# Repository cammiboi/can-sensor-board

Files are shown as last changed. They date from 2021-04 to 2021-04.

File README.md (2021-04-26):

# can-sensor-board

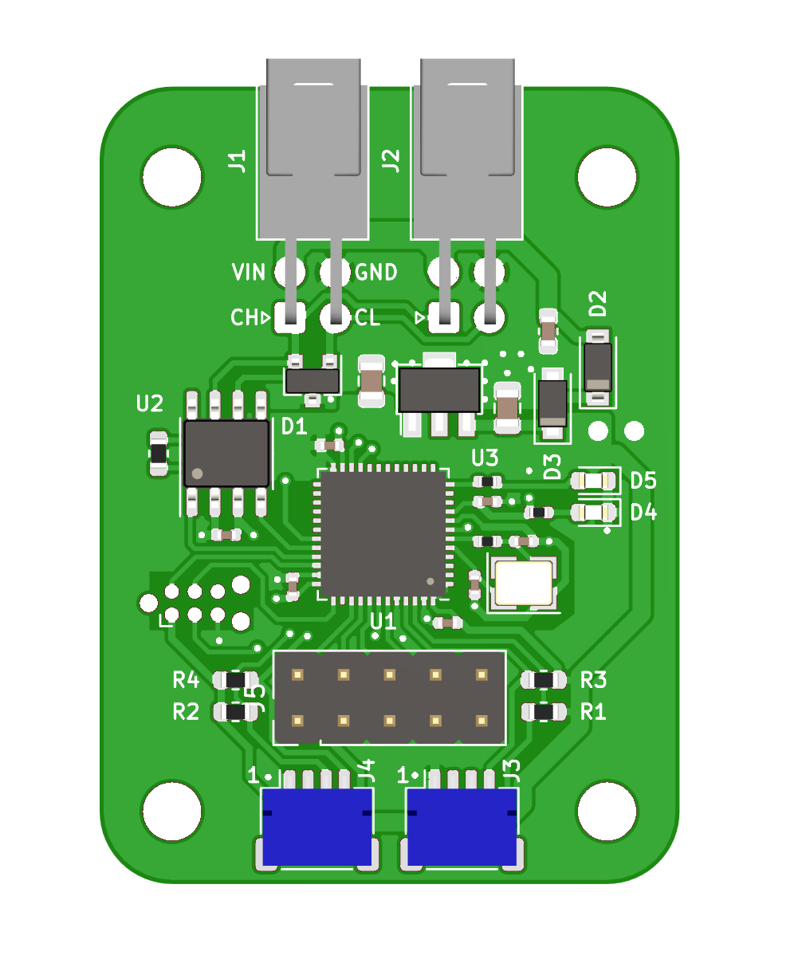
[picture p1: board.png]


# Pupose
To attach any I2C sensor to a CAN bus.

# Requirements
* Powered by 5-16V DC
* Input and output connector (daisy chain boards)
* Set address on board
* I2C 4 pin connector to quickly connect different sensor boards
* Programming header
* ESD protection on connector pins

# Pinout
### CAN and Power Connectors (J1 and J2)

Both of these connectors are the same, you can plug input OR output in to either one.

Wire connector: Molex 1053081204

| Pin Number | Function |
|--|--|
|1| CAN H |
|2 | CAN L |
|3 | VIN |
|4 | GND|

### I2C Connectors (J3 and J4)

Works with Sensor boards that have Adafruit STEMMA QT or Sparkfun QWIIC connector.

| Pin Number | Function |
|--|--|
|1| GND |
|2 | 3V3 |
|3 | SDA |
|4 | SCL|

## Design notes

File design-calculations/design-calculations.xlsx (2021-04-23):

https://datasheet.lcsc.com/lcsc/1912111437_TAE-Zhejiang-Abel-Elec-TAXM8M4RDBCCT2T_C400090.pdf
http://www.raltron.com/wp-content/uploads/2016/11/Oscillator-design-guide-for-STM8S-STM8A-and-STM32-microcontrollers-ST-MICRO-1.pdf
1. Check cystal gain margin
ESR | 250 | ohm
f | 8000000 | Hz
Co | 7e-12 | F | shunt cap
Cl | 1e-11 | F | norm load cap
gmcrit | 0.73 | mA/V
gm | 10 | mA/V
gmargin | 13.7 |  | ensure >5
2. Calculate load cap value
Cs | 5e-12 | F | stray pcb cap
Cl | 1e-11
3. Calculate drive level and Rext
Initial estimation of Rext
Rext(est) | 1989.436789 | ohm

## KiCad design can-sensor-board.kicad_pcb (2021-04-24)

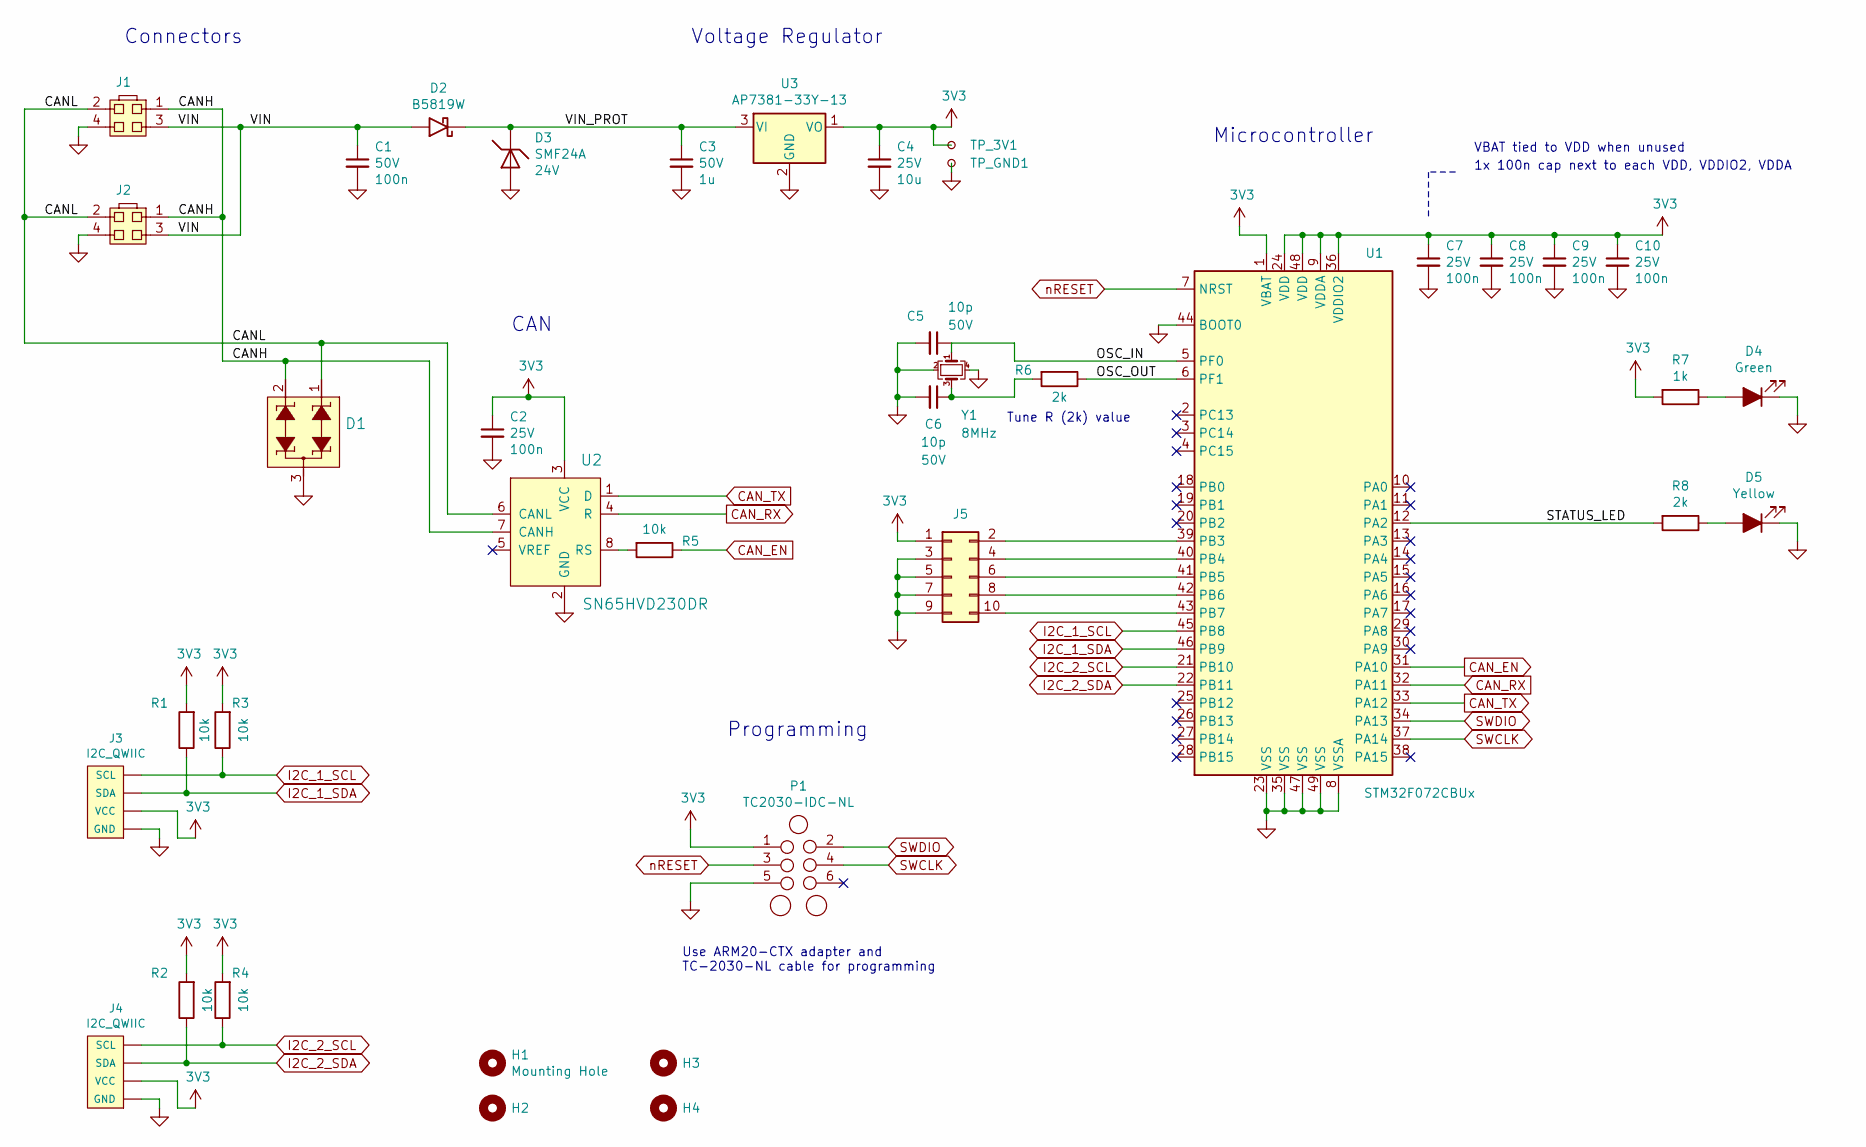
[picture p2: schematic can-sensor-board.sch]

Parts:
C1: C_0603_50V_X7R_100n; C_0603_1608Metric; Voltage 50V; Part Number CL10B104KB8NFNC; JLC C14663
C2, C7, C8, C9, C10: C_0402_25V_X7R_100n; C_0402_1005Metric; Voltage 25V; Manufacturer Part Number CL05B104KA5NNNC; JLC C100072
C3: C_0805_50V_X7R_1u; C_0805_2012Metric; Voltage 50V; Part Number CL21B105KBFNNNG; JLC C28323
C4: C_0805_25V_X5R_10u; C_0805_2012Metric; Voltage 25V; Part Number CL21A106KAYNNNG; JLC C15850
C5, C6: C_0402_50V_COG_10p; C_0402_1005Metric; Voltage 50V; JLC C32949
D1: PESD2CAN_215; SOT-23; MPN PESD2CAN,215; Digi-Key_PN 1727-3891-1-ND
D2: B5819W; D_SOD-123; Voltage 40V; JLC C8598
D3: SMF24A; D_SOD-123F; JLC C169430
D4: LED_0603_Green; LED_0603_1608Metric; JLC C72043
D5: LED_0603_Yellow; LED_0603_1608Metric; JLC C72038
H1, H2, H3, H4: Mounting Hole; MountingHole_3.2mm_M3; JLCPCB_IGNORE Yes
J1, J2: 105314-1104; Molex_Nano-Fit_105314-xx04_2x02_P2.50mm_Horizontal; JLCPCB_IGNORE Yes
J3, J4: I2C_QWIIC; JST_SH_SM04B-SRSS-TB_1x04-1MP_P1.00mm_Horizontal; Part Number SM04B-SRSS-TB(LF)(SN); JLC C395301
J5: Conn_02x05_Odd_Even; PinHeader_2x05_P2.54mm_Vertical; JLCPCB_IGNORE Yes
P1: TC2030-IDC-NL; Tag-Connect_TC2030-IDC-NL_2x03_P1.27mm_Vertical; JLCPCB_IGNORE Yes
R1, R2, R3, R4, R5: R_0603_10k_1; R_0603_1608Metric; JLC C25804
R6, R8: R_0402_2k_1; R_0402_1005Metric; JLC C4109
R7: R_0402_1k_1; R_0402_1005Metric; JLC C11702
TP_3V1: TestPoint_Small; TestPoint_Pad_D1.00mm; JLCPCB_IGNORE Yes
TP_GND1: TestPoint_Small; TestPoint_Pad_D1.00mm; JLCPCB_IGNORE Yes
U1: STM32F072CBUx; QFN-48-1EP_7x7mm_P0.5mm_EP5.6x5.6mm; JLC C92504
U2: SN65HVD230DR; SOIC-8_3.9x4.9mm_P1.27mm; MPN SN65HVD230DR; Digi-Key_PN 296-11654-1-ND
U3: AP7381-33Y-13; SOT-89-3; JLC C460411
Y1: TAXM8M4RDBCCT2T; Crystal_SMD_3225-4Pin_3.2x2.5mm; JLC C400090

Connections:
3V3: C2.1, C4.1, C7.1, C8.1, C9.1, C10.1, J3.2 (VCC), J4.2 (VCC), J5.1, P1.1, R1.2, R2.2, R3.2, R4.2, R7.2, TP_3V1.1, U1.1 (VBAT), U1.9 (VDDA), U1.24 (VDD), U1.36 (VDDIO2), U1.48 (VDD), U2.3 (VCC), U3.1 (VO)
/CANH: D1.2 (C2), J1.1, J2.1, U2.7 (CANH)
/CANL: D1.1 (C1), J1.2, J2.2, U2.6 (CANL)
/OSC_IN: C5.1, U1.5 (PF0), Y1.1
/OSC_OUT: R6.1, U1.6 (PF1)
/STATUS_LED: R8.2, U1.12 (PA2)
/VIN: C1.1, D2.2 (A), J1.3, J2.3
/VIN_PROT: C3.1, D2.1 (K), D3.1 (A1), U3.3 (VI)
CAN_EN: R5.1, U1.31 (PA10)
CAN_RX: U1.32 (PA11), U2.4 (R)
CAN_TX: U1.33 (PA12), U2.1 (D)
GND: C1.2, C2.2, C3.2, C4.2, C5.2, C6.2, C7.2, C8.2, C9.2, C10.2, D1.3 (C3), D3.2 (A2), D4.1 (K), D5.1 (K), J1.4 (3), J2.4 (3), J3.1 (GND), J4.1 (GND), J5.3, J5.5, J5.7, J5.9, P1.5, TP_GND1.1, U1.8 (VSSA), U1.23 (VSS), U1.35 (VSS), U1.44 (BOOT0), U1.47 (VSS), U1.49 (VSS), U2.2 (GND), U3.2 (GND), Y1.2, Y1.4
I2C_1_SCL: J3.4 (SCL), R3.1, U1.45 (PB8)
I2C_1_SDA: J3.3 (SDA), R1.1, U1.46 (PB9)
I2C_2_SCL: J4.4 (SCL), R4.1, U1.21 (PB10)
I2C_2_SDA: J4.3 (SDA), R2.1, U1.22 (PB11)
unnamed: C6.1, R6.2, Y1.3
unnamed: D4.2 (A), R7.1
unnamed: D5.2 (A), R8.1
unnamed: J5.2, U1.39 (PB3)
unnamed: J5.4, U1.40 (PB4)
unnamed: J5.6, U1.41 (PB5)
unnamed: J5.8, U1.42 (PB6)
unnamed: J5.10, U1.43 (PB7)
unnamed: R5.2, U2.8 (RS)
SWCLK: P1.4, U1.37 (PA14)
SWDIO: P1.2, U1.34 (PA13)
nRESET: P1.3, U1.7 (NRST)

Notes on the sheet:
Microcontroller
Connectors
Voltage Regulator
CAN
VBAT tied to VDD when unused
1x 100n cap next to each VDD, VDDIO2, VDDA
Use ARM20-CTX adapter and TC-2030-NL cable for programming
Programming
Tune R (2k) value

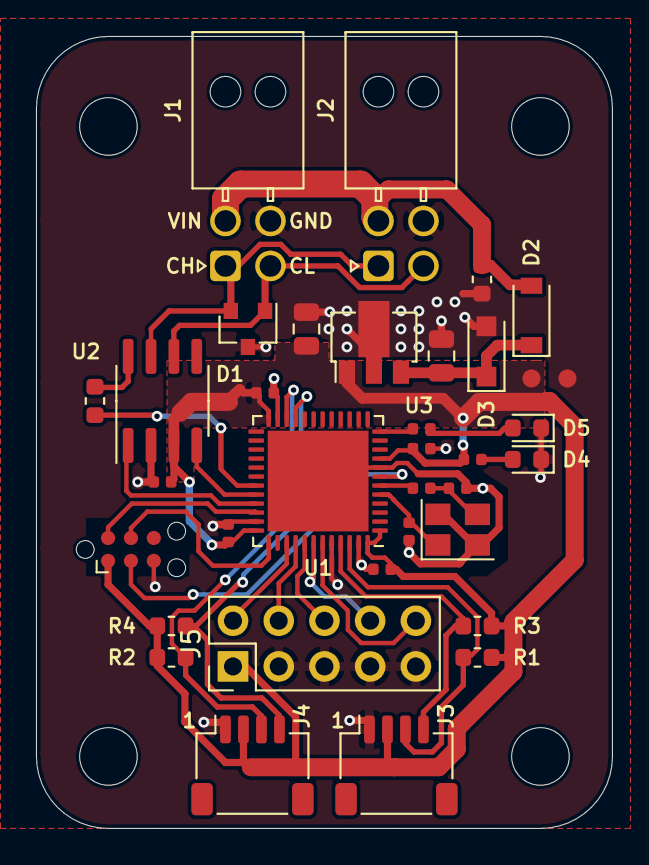
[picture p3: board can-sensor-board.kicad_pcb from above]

Board: 2 copper layers, 32.0 x 44.0 mm, 39 parts (0 on the bottom side), 28 nets.

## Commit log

2021-04-23 schematic done
    [can-sensor-board.kicad_pcb, can-sensor-board.sch, design-calculations.xlsx]
2021-04-24 final v1 board
    [can-sensor-board.kicad_pcb, can-sensor-board.sch]
2021-04-24 final v1 submitted for review
    [can-sensor-board.kicad_pcb, can-sensor-board.sch]
